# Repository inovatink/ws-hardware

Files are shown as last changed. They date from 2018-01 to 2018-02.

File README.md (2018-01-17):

# Wearable Sensor Hardware

## Description

In this repository you can find all of the necessary materials to; 
- understand what was done 
- manufacture hardware (Electronics + 3D print)
- program Arduino bootloader
- setup microcontroller

# Important Notice

If you decide to modify any parts of the project make sure you keep it open source and share with us. Keep up the good work.

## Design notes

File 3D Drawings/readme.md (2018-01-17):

# 3D Drawings

Here are Solidworks parts of bottom and top piece of wearable sensor enclosure and also STL parts that can be 3D printed.

The sensor enclosure consists of 2 parts, top and bottom;

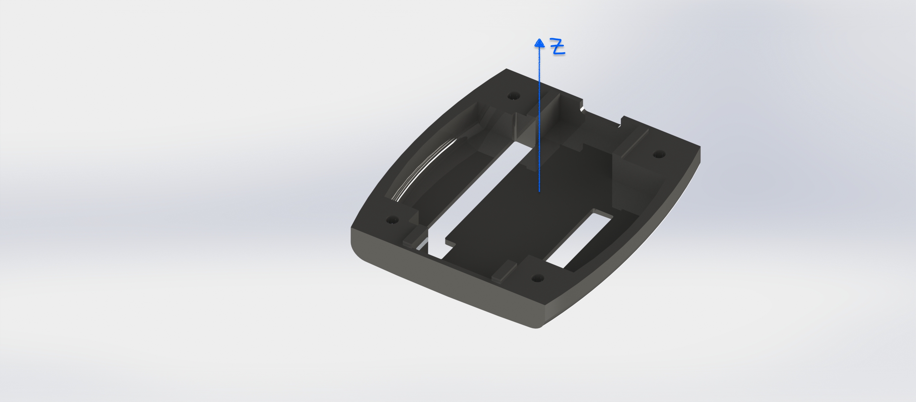
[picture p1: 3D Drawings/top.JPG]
Top
Top: 

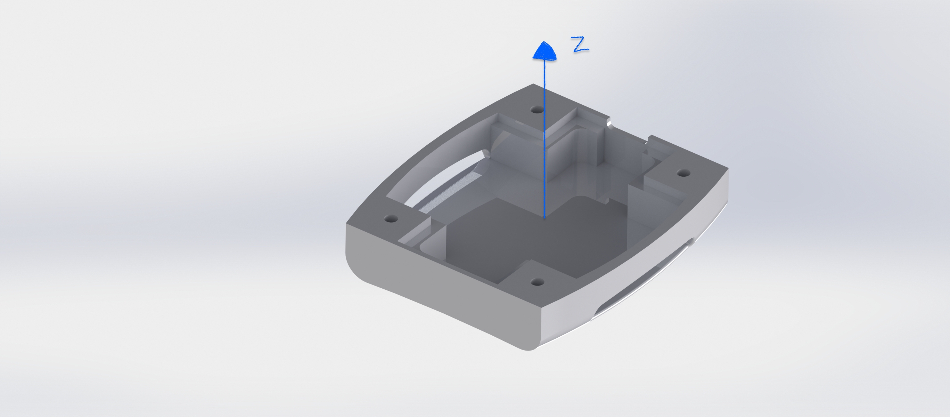
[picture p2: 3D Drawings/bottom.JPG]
Bottom
Bottom:

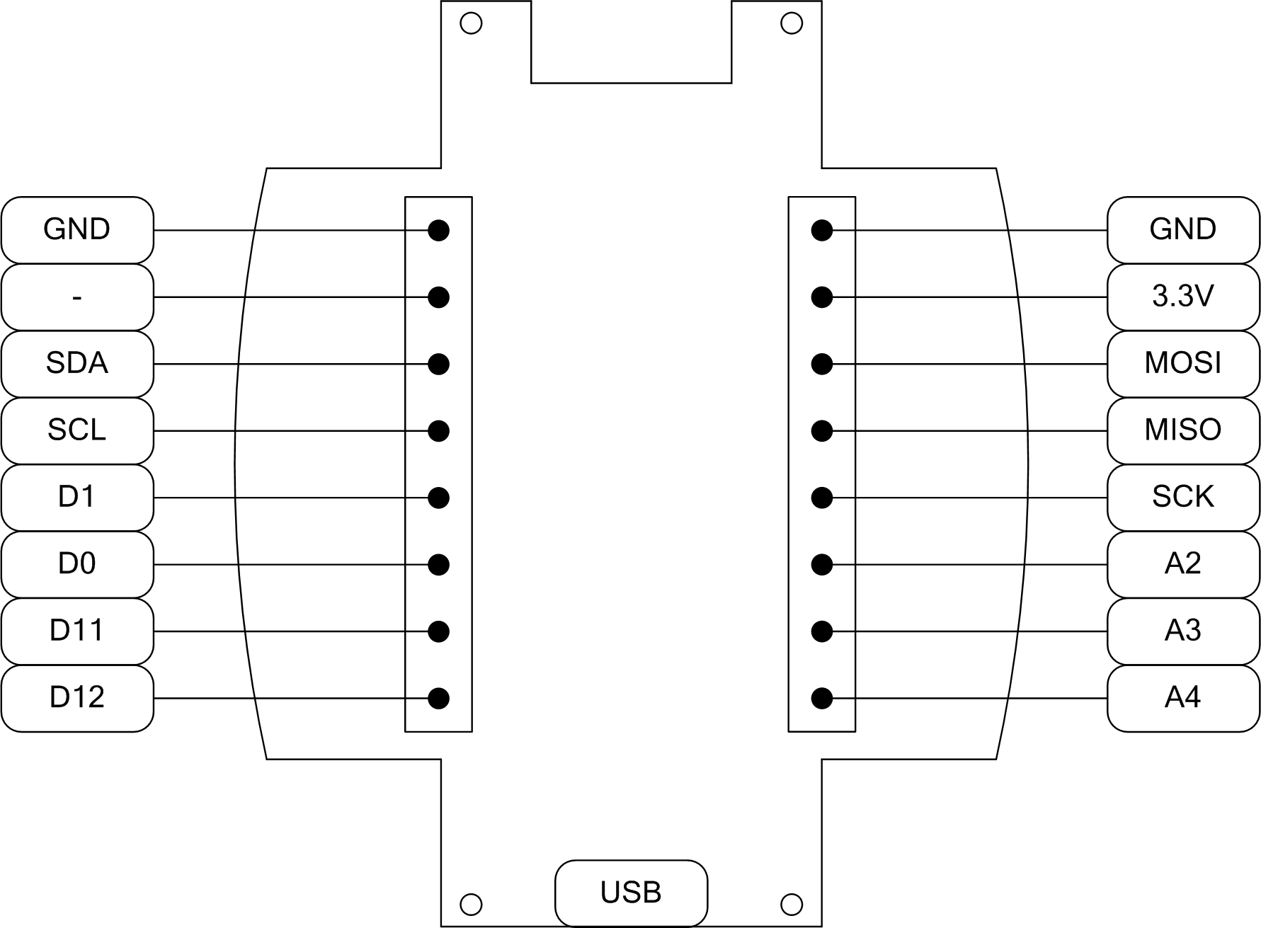
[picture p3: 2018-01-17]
ws_v2_external_pinout.png

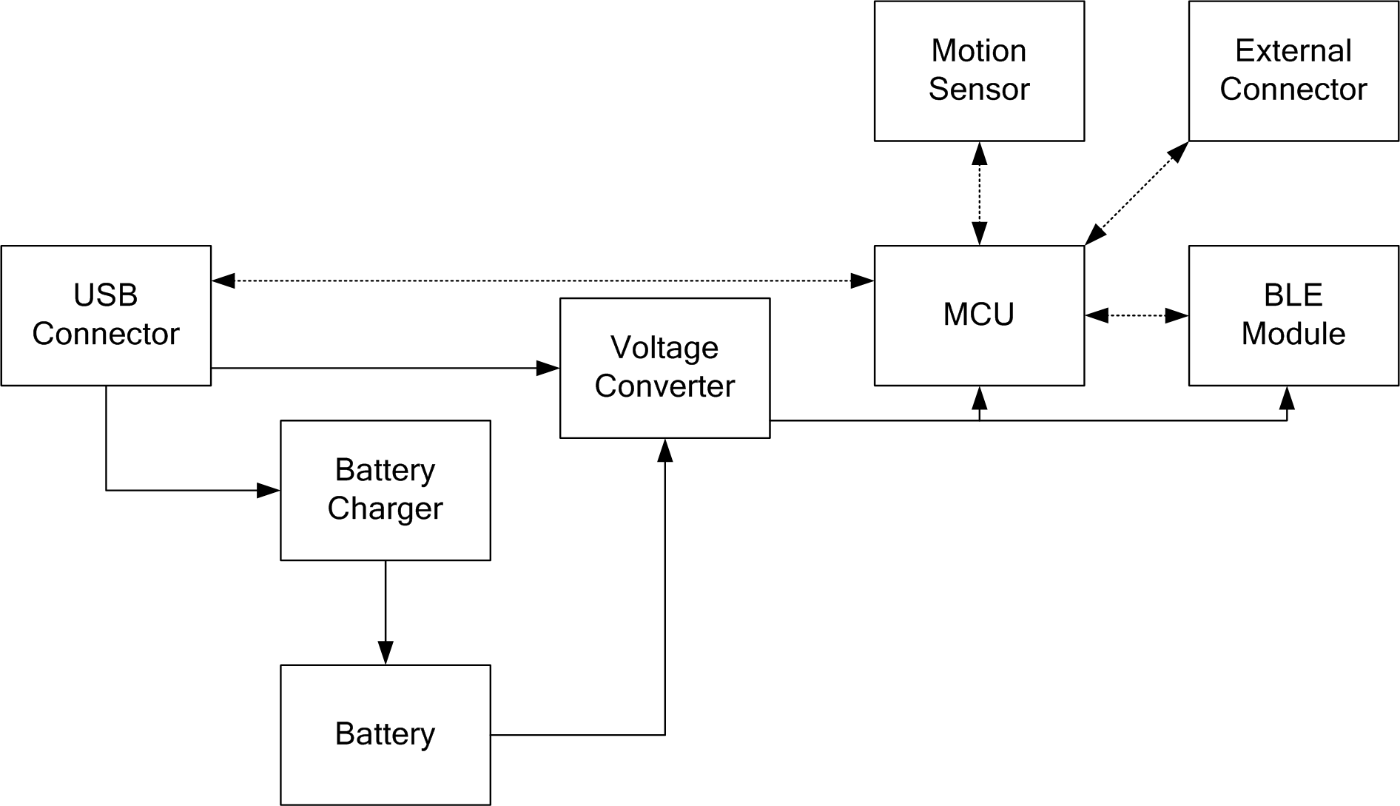
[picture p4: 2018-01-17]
ws_v2_block_diagram.png

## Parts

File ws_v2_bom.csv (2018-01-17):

Part | Value | Package | Mfg. Part No. | Datasheet
B1 | button | KMR2 | KMR231NG LFS | https://www.ckswitches.com/media/1479/kmr2.pdf
C1 | 0.1u | C0805
C2 | 10u | C0805
C3 | 0.1u | C0805
C4 | 10u | C0805
C5 | 0.1u | C0805
C6 | 10u | C0805
C7 | 0.1u | C0805
C8 | 10u | C0805
C9 | 0.1u | C0805
C11 | 0.1u | C0805
C12 | 1u | "C0805"
C13 | 0.1u | C0805
C14 | 0.1u | C0805
C15 | 0.1u | C0805
C17 | 0.1u | C0805
C18 | 0.1u | C0805
C19 | 0.1u | C0805
C20 | 0.1u | C0805
D1 |  | SOD-323F | ZLLS410TA | https://www.diodes.com/assets/Datasheets/ZLLS410.pdf
IC1 | RN4871 | RN4871 | RN4871-V/RM118 | http://ww1.microchip.com/downloads/en/DeviceDoc/50002489C.pdf
IC2 | ATSAMD21G-A | TQFP-48 | ATSAMD21G18A-AUT | http://ww1.microchip.com/downloads/en/DeviceDoc/40001882A.pdf
IC3 | AP2112K-3.3V | SOT23-5 | AP2112K-3.3TRG1 | https://www.diodes.com/assets/Datasheets/AP2112.pdf
IC4 | MCP73831 | SOT23-5 | MCP73831T-2ACI/OT | http://ww1.microchip.com/downloads/en/DeviceDoc/20001984g.pdf
IC5 | MPU-9250 |  | MPU-9250 | https://store.invensense.com/datasheets/invensense/MPU9250REV1.0.pdf
J1 |  | 1X08_SMD_MALE | 91601-308LF | https://cdn.amphenol-icc.com/media/wysiwyg/files/drawing/91601.pdf
J2 |  | 1X08_SMD_MALE | 91601-308LF | https://cdn.amphenol-icc.com/media/wysiwyg/files/drawing/91601.pdf
L1 | ferrite_bead | L0805 | MH2029-601Y | http://www.bourns.com/docs/Product-Datasheets/mh.pdf
LED1 | AMBER | CHIP-LED0805
LED2 | GREEN | CHIP-LED0805
LED3 | BLUE | CHIP-LED0805
R1 | 10k | R0805
R2 | tbd | R0805
R3 | tbd | R0805
R4 | 100k | R0805
R5 | 100k | R0805
R6 | tbd | R0805
R7 | tbd | R0805
R8 | 100k | R0805
R12 | 100k | R0805
R13 | 10k | R0805
R14 | 10k | R0805
X1 | USB | USB - micro B | 10118194-0001LF | https://cdn.amphenol-icc.com/media/wysiwyg/files/documentation/datasheet/inputoutput/io_usb_micro.pdf
X2 | BATTERY | JST_2PIN-SMT-RA | S2B-PH-SM4-TB(LF)(SN) | http://www.jst-mfg.com/product/pdf/eng/ePH.pdf
X3 | DEBUG | 2X5-PTH-1.27MM | 20021111-00010T4LF | https://cdn.amphenol-icc.com/media/wysiwyg/files/drawing/20021111.pdf
X4 | HRM | 1X5-PTH-2.54MM

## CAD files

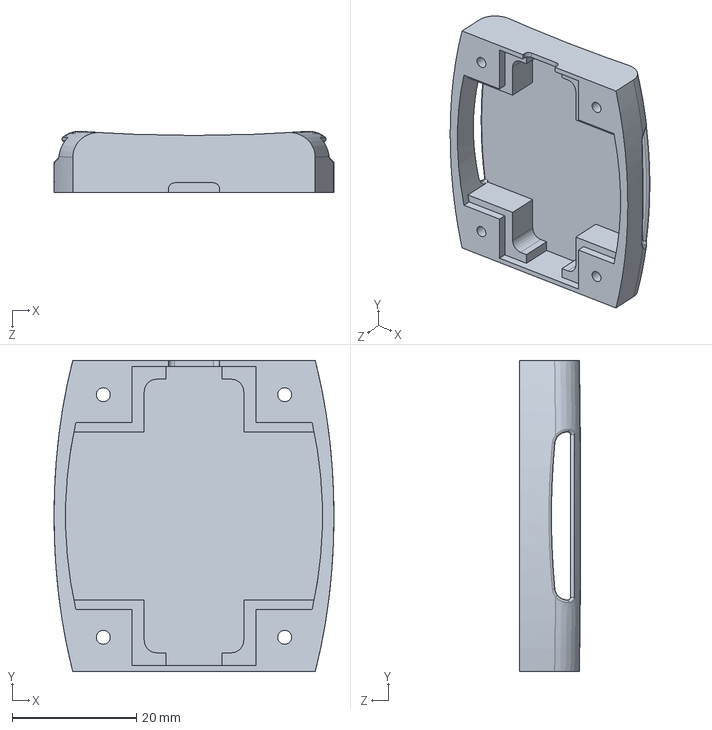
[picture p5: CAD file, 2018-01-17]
3D Drawings/Solidworks Files/Bottom.SLDPRT
45.0 x 50.0 x 9.86 mm

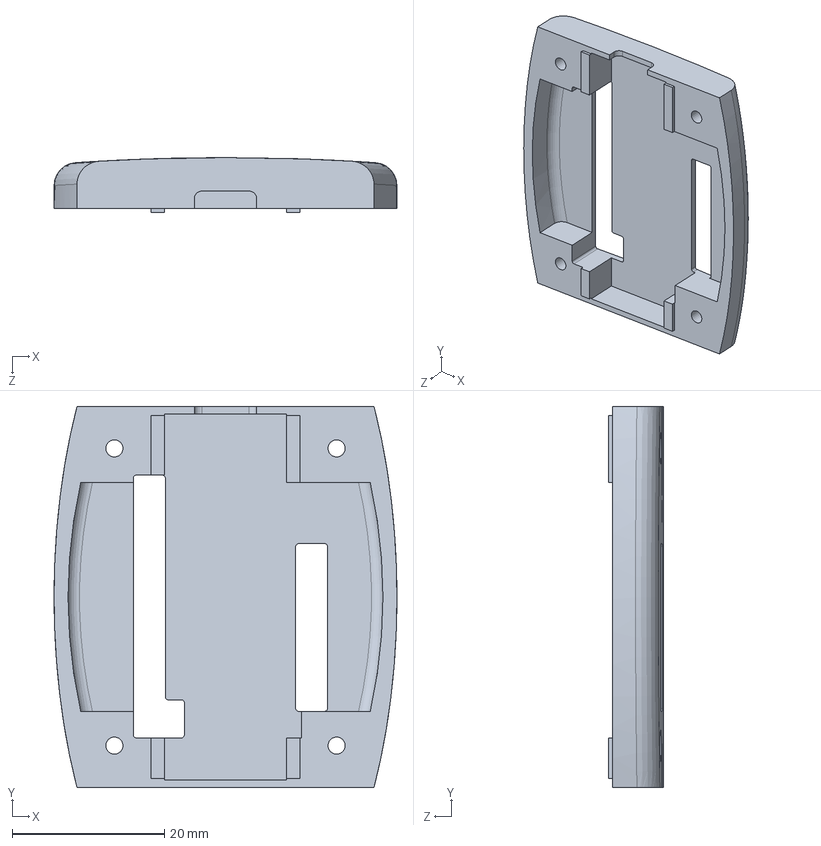
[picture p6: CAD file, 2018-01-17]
3D Drawings/Solidworks Files/Top.SLDPRT
45.0 x 50.0 x 7.20 mm

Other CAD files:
3D Drawings/STL Files/Bottom.STL
3D Drawings/STL Files/Top.STL

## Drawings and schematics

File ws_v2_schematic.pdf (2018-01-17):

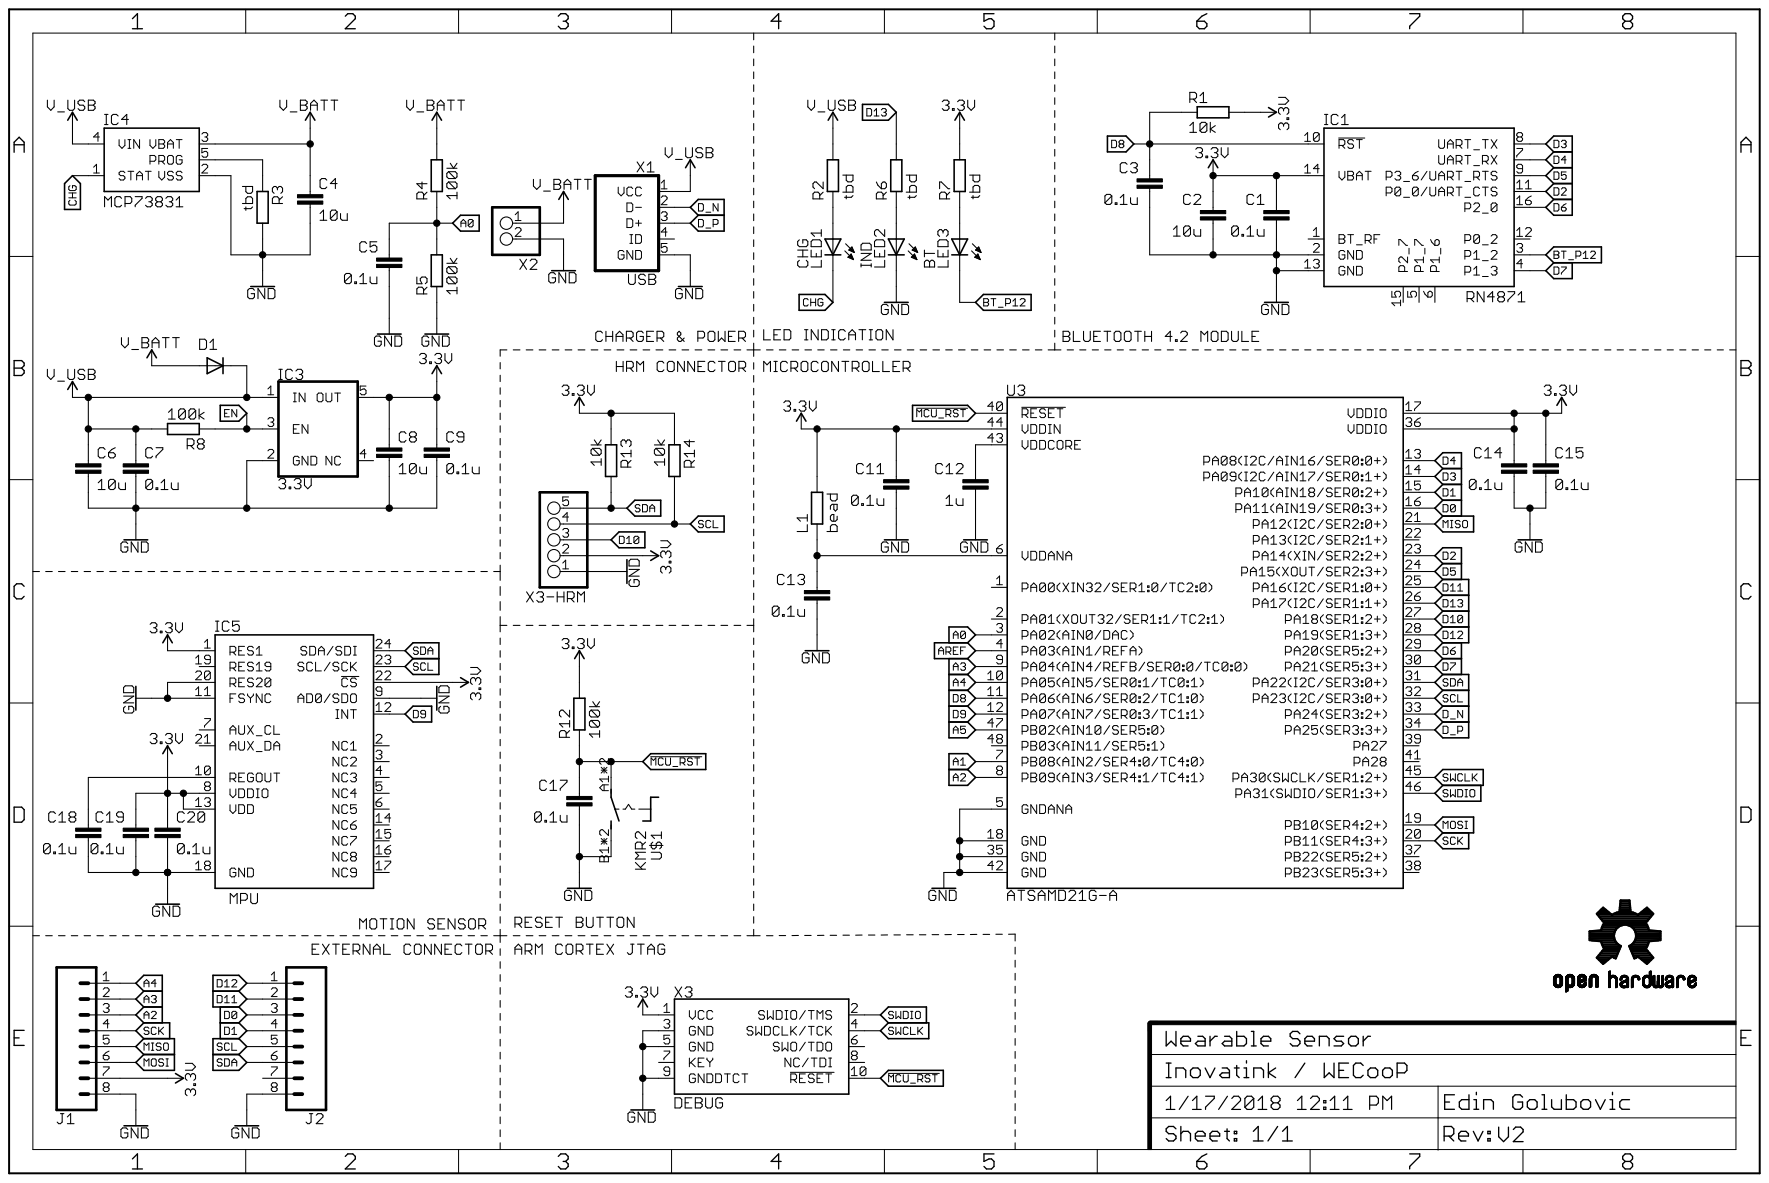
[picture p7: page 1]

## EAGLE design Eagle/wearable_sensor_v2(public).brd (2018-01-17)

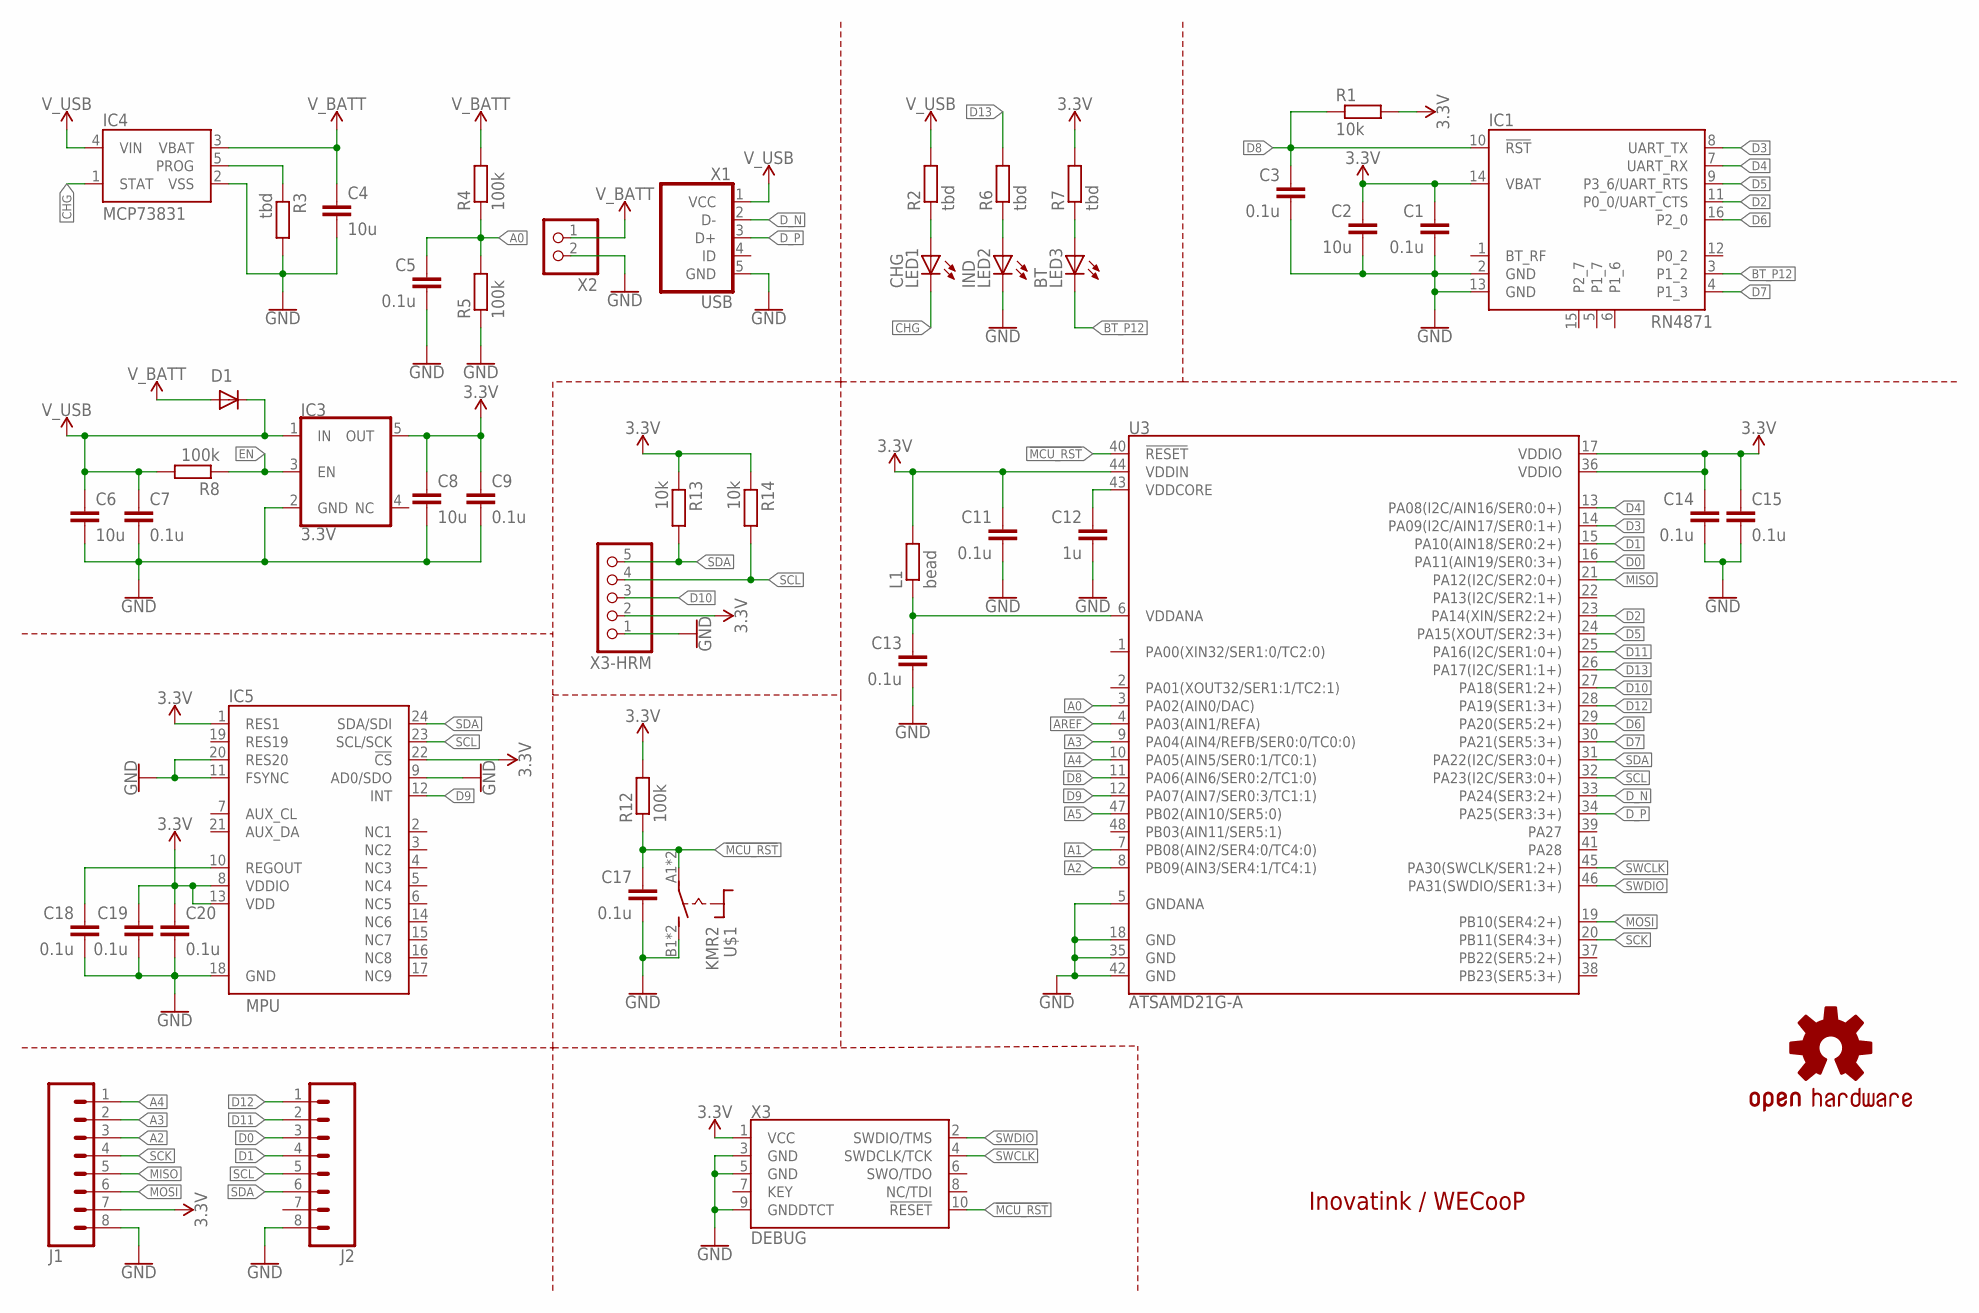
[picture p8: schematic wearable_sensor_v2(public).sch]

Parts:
C1, C3, C5, C7, C9, C11, C13, C14, C15, C17, C18, C19, C20: 0.1u; C0805
C2, C4, C6, C8: 10u; C0805
C12: 1u; C0805
D1: DIODESOD-323F; SOD-323F
IC1: RN4871
IC3: 3.3V; SOT23-5
IC4: MCP73831; SOT23-5
IC5: MPU; MPU9250
J1, J2: CONN_08SMD-MALE; 1X08_SMD_MALE
L1: bead; R0805
LED1: CHG; CHIP-LED0805
LED2: IND; CHIP-LED0805
LED3: BT; CHIP-LED0805
LOGO1: OSHW-LOGOMINI; OSHW-LOGO-MINI
R1, R13, R14: 10k; R0805
R2, R3, R6, R7: tbd; R0805
R4, R5, R8, R12: 100k; R0805
U3: ATSAMD21G-A; TQFP-48
U$1: KMR2
X1: USB; 10118194-0001LF
X2: JST_2PIN-SMT-RA; JST-PH-2-SMT-RA
X3: DEBUG; 2X5-PTH-1.27MM
X3-HRM: PINHD-1X5; 1X05

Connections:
3.3V: C1.1, C2.1, C8.1, C9.1, C11.1, C14.1, C15.1, C19.1, C20.1, IC1.14 (VBAT), IC3.5 (OUT), IC5.1 (RES1), IC5.8 (VDDIO), IC5.13 (VDD), IC5.22 (!CS), J1.7, L1.2, R1.2, R7.2, R12.2, R13.1, R14.1, U3.17 (VDDIO), U3.36 (VDDIO), U3.44 (VDDIN), X3.1 (VCC), X3-HRM.2
!MCU_RST: C17.1, R12.1, U3.40 (!RESET!), U$1.A1, U$1.A2, X3.10 (!RESET)
A0: C5.1, R4.1, R5.2, U3.3 (PA02(AIN0/DAC))
A1: U3.7 (PB08(AIN2/SER4:0/TC4:0))
A2: J1.3, U3.8 (PB09(AIN3/SER4:1/TC4:1))
A3: J1.2, U3.9 (PA04(AIN4/REFB/SER0:0/TC0:0))
A4: J1.1, U3.10 (PA05(AIN5/SER0:1/TC0:1))
A5: U3.47 (PB02(AIN10/SER5:0))
AREF: U3.4 (PA03(AIN1/REFA))
BT_P12: IC1.3 (P1_2), LED3.C
CHG: IC4.1 (STAT), LED1.C
D0: J2.3, U3.16 (PA11(AIN19/SER0:3+))
D1: J2.4, U3.15 (PA10(AIN18/SER0:2+))
D2: IC1.11 (P0_0/UART_CTS), U3.23 (PA14(XIN/SER2:2+))
D3: IC1.8 (UART_TX), U3.14 (PA09(I2C/AIN17/SER0:1+))
D4: IC1.7 (UART_RX), U3.13 (PA08(I2C/AIN16/SER0:0+))
D5: IC1.9 (P3_6/UART_RTS), U3.24 (PA15(XOUT/SER2:3+))
D6: IC1.16 (P2_0), U3.29 (PA20(SER5:2+))
D7: IC1.4 (P1_3), U3.30 (PA21(SER5:3+))
D8: C3.1, IC1.10 (!RST), R1.1, U3.11 (PA06(AIN6/SER0:2/TC1:0))
D9: IC5.12 (INT), U3.12 (PA07(AIN7/SER0:3/TC1:1))
D10: U3.27 (PA18(SER1:2+)), X3-HRM.3
D11: J2.2, U3.25 (PA16(I2C/SER1:0+))
D12: J2.1, U3.28 (PA19(SER1:3+))
D13: R6.2, U3.26 (PA17(I2C/SER1:1+))
D_N: U3.33 (PA24(SER3:2+)), X1.2 (D-)
D_P: U3.34 (PA25(SER3:3+)), X1.3 (D+)
EN: IC3.3 (EN), R8.1
GND: C1.2, C2.2, C3.2, C4.2, C5.2, C6.2, C7.2, C8.2, C9.2, C11.2, C12.2, C13.2, C14.2, C15.2, C17.2, C18.2, C19.2, C20.2, IC1.2 (GND), IC1.13 (GND), IC3.2 (GND), IC4.2 (VSS), IC5.9 (AD0/SDO), IC5.11 (FSYNC), IC5.18 (GND), IC5.20 (RES20), J1.8, J2.8, LED2.C, R3.2, R5.1, U3.5 (GNDANA), U3.18 (GND), U3.35 (GND), U3.42 (GND), U$1.B1 (S), U$1.B2 (S), X1.5 (GND), X2.2 (1), X3.3 (GND), X3.5 (GND), X3.9 (GNDDTCT), X3-HRM.1
MISO: J1.5, U3.21 (PA12(I2C/SER2:0+))
MOSI: J1.6, U3.19 (PB10(SER4:2+))
unnamed: LED2.A, R6.1
unnamed: LED1.A, R2.1
unnamed: IC4.5 (PROG), R3.1
unnamed: LED3.A, R7.1
unnamed: C18.1, IC5.10 (REGOUT)
unnamed: C13.1, L1.1, U3.6 (VDDANA)
unnamed: C12.1, U3.43 (VDDCORE)
SCK: J1.4, U3.20 (PB11(SER4:3+))
SCL: IC5.23 (SCL/SCK), J2.5, R14.2, U3.32 (PA23(I2C/SER3:0+)), X3-HRM.4
SDA: IC5.24 (SDA/SDI), J2.6, R13.2, U3.31 (PA22(I2C/SER3:0+)), X3-HRM.5
SWCLK: U3.45 (PA30(SWCLK/SER1:2+)), X3.4 (SWDCLK/TCK)
SWDIO: U3.46 (PA31(SWDIO/SER1:3+)), X3.2 (SWDIO/TMS)
V_BATT: C4.1, D1.A, IC4.3 (VBAT), R4.2, X2.1 (2)
V_USB: C6.1, C7.1, D1.C, IC3.1 (IN), IC4.4 (VIN), R2.2, R8.2, X1.1 (VCC)

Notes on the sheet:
Inovatink / WECooP

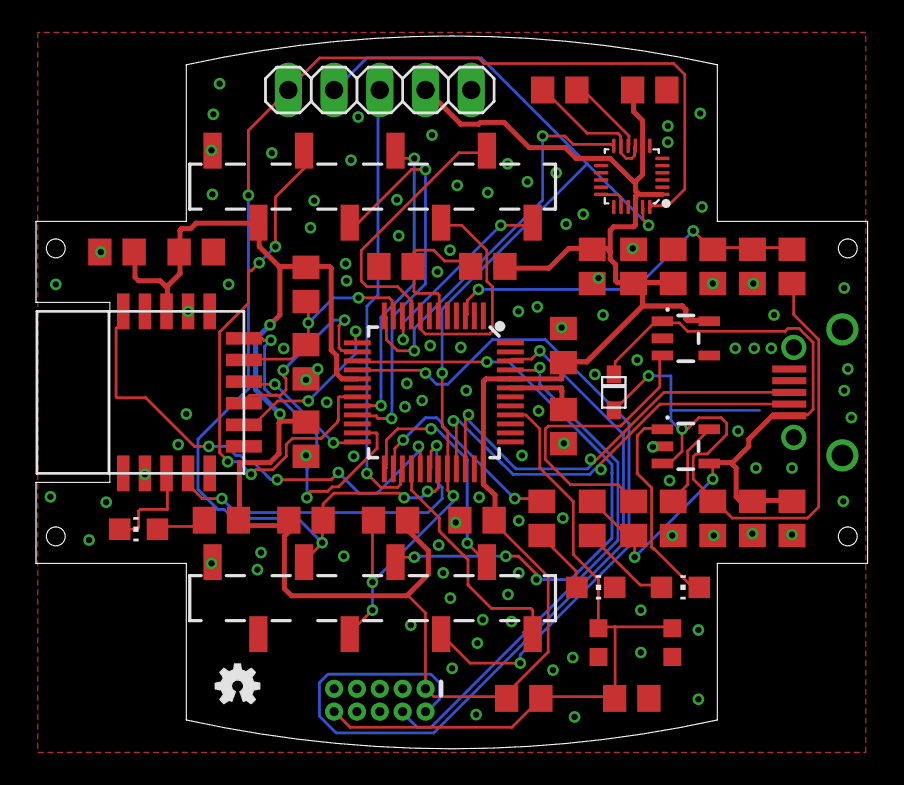
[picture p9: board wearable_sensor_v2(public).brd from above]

Board: 2 copper layers, 46.2 x 39.6 mm, 47 parts (1 on the bottom side), 42 nets.

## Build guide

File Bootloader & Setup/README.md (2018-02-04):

# Bootloader and Initial Setup

## Necessary Tools

- ARM Cortex JTAG (ATMEL-ICE, SAM-ICE or equivalent )

## Procedure

Below procedure explains how to program the bootloader into the wearable sensor board and how to change variant.cpp, variant.h and boards.txt files in order to have wearable sensor working with Arduino enviroment.

> If you already have board with Arduino bootloader you can skip step 1.

> This repo  includes the changed boards.txt, variant.cpp and varian.h files. This files were changed for Arduino version 1.8.5 (Windows) and Arduino SAMD Boards package version 1.6.17. If you have different version of Arduino and SAMD board package it is recommended that you go through procedure given below. Otherwise just download these files and replace the original ones in the corresponding folders and you will be all set.

1. Flash Board with bootloader circuitplay_m0_samd21g18_sam_ba.bin from https://github.com/arduino/ArduinoCore-samd/tree/master/bootloaders/circuitplay (also found in this repo)
2. Install latest Arduino IDE 
3. Install latest SAMD board package (Boards Manager)
4. In AppData\Local\Arduino15\packages\arduino\hardware\samd\1.6.xx folder in boards.txt file under the section named # Arduino/Genuino Zero (Native USB Port) insert -DCRYSTALLESS flag in; 	
```cpp 
arduino_zero_native.build.extra_flags=-D__SAMD21G18A__ {build.usb_flags}
```
This operation shoud result in line like shown below;

```cpp
arduino_zero_native.build.extra_flags= -DCRYSTALLESS -D__SAMD21G18A__ {build.usb_flags}
```

5. In variant.cpp from \packages\arduino\hardware\samd\1.6.xx\variants\arduino_zero change pin description in PinDescription g_APinDescription

- Comment out:
```cpp
{ PORTA,  9, PIO_TIMER, (PIN_ATTR_DIGITAL|PIN_ATTR_PWM|PIN_ATTR_TIMER), No_ADC_Channel, PWM0_CH1, TCC0_CH1, EXTERNAL_INT_9 },]
{ PORTA,  8, PIO_TIMER, (PIN_ATTR_DIGITAL|PIN_ATTR_PWM|PIN_ATTR_TIMER), No_ADC_Channel, PWM0_CH0, TCC0_CH0, EXTERNAL_INT_NMI },
```

- Replace with
```cpp
{ PORTA,  9, PIO_SERCOM_ALT, (PIN_ATTR_DIGITAL), No_ADC_Channel,NOT_ON_PWM, NOT_ON_TIMER, EXTERNAL_INT_9 },
{ PORTA,  8, PIO_SERCOM_ALT, (PIN_ATTR_DIGITAL), No_ADC_Channel, NOT_ON_PWM, NOT_ON_TIMER, EXTERNAL_INT_NMI },
```
- Add following code at the end of variant.cpp
```cpp
Uart Serial2( &sercom2, PIN_SERIAL2_RX, PIN_SERIAL2_TX, PAD_SERIAL2_RX, PAD_SERIAL2_TX);		

void SERCOM2_Handler(){
	Serial2.IrqHandler();
	}
```

6. In variant.h under the same folder add following code in the SERCOM DEFINITION
```cpp
extern Uart Serial2;    // Serial2 definition
```

- Also add serial2 pin definition as shown below

```cpp	
#define PIN_SERIAL2_RX       (3ul)                 // Pin description number for PIO_SERCOM on D3
#define PIN_SERIAL2_TX       (4ul)                 // Pin description number for PIO_SERCOM on D4
#define PAD_SERIAL2_TX       (UART_TX_PAD_0)       // SERCOM pad 0
#define PAD_SERIAL2_RX       (SERCOM_RX_PAD_1)     // SERCOM pad 1`
```

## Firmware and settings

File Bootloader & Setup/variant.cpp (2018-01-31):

/*
  Copyright (c) 2014-2015 Arduino LLC.  All right reserved.

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
  You should have received a copy of the GNU Lesser General Public
  License along with this library; if not, write to the Free Software
  Foundation, Inc., 51 Franklin St, Fifth Floor, Boston, MA  02110-1301  USA
*/
/*
 * +------------+------------------+--------+-----------------+--------------------------------------------------------------------------------------------------------
 * + Pin number +  ZERO Board pin  |  PIN   | Label/Name      | Comments (* is for default peripheral in use)
 * +------------+------------------+--------+-----------------+--------------------------------------------------------------------------------------------------------
 * |            | Digital Low      |        |                 |
 * +------------+------------------+--------+-----------------+--------------------------------------------------------------------------------------------------------
 * | 0          | 0 -> RX          |  PA11  |                 | EIC/EXTINT[11] ADC/AIN[19]           PTC/X[3] *SERCOM0/PAD[3]  SERCOM2/PAD[3]  TCC0/WO[3]  TCC1/WO[1]
 * | 1          | 1 <- TX          |  PA10  |                 | EIC/EXTINT[10] ADC/AIN[18]           PTC/X[2] *SERCOM0/PAD[2]                  TCC0/WO[2]  TCC1/WO[0]
 * | 2          | 2                |  PA14  |                 | EIC/EXTINT[14]                                 SERCOM2/PAD[2]  SERCOM4/PAD[2]  TC3/WO[0]   TCC0/WO[4]
 * | 3          | ~3               |  PA09  |                 | EIC/EXTINT[9]  ADC/AIN[17]           PTC/X[1]  SERCOM0/PAD[1]  SERCOM2/PAD[1] *TCC0/WO[1]  TCC1/WO[3]
 * | 4          | ~4               |  PA08  |                 | EIC/NMI        ADC/AIN[16]           PTC/X[0]  SERCOM0/PAD[0]  SERCOM2/PAD[0] *TCC0/WO[0]  TCC1/WO[2]
 * | 5          | ~5               |  PA15  |                 | EIC/EXTINT[15]                                 SERCOM2/PAD[3]  SERCOM4/PAD[3] *TC3/WO[1]   TCC0/WO[5]
 * | 6          | ~6               |  PA20  |                 | EIC/EXTINT[4]                        PTC/X[8]  SERCOM5/PAD[2]  SERCOM3/PAD[2]             *TCC0/WO[6]
 * | 7          | 7                |  PA21  |                 | EIC/EXTINT[5]                        PTC/X[9]  SERCOM5/PAD[3]  SERCOM3/PAD[3]              TCC0/WO[7]
 * +------------+------------------+--------+-----------------+--------------------------------------------------------------------------------------------------------
 * |            | Digital High     |        |                 |
 * +------------+------------------+--------+-----------------+--------------------------------------------------------------------------------------------------------
 * | 8          | ~8               |  PA06  |                 | EIC/EXTINT[6]  ADC/AIN[6]  AC/AIN[2] PTC/Y[4]  SERCOM0/PAD[2]                 *TCC1/WO[0]
 * | 9          | ~9               |  PA07  |                 | EIC/EXTINT[7]  ADC/AIN[7]  AC/AIN[3] PTC/Y[5]  SERCOM0/PAD[3]                 *TCC1/WO[1]
 * | 10         | ~10              |  PA18  |                 | EIC/EXTINT[2]                        PTC/X[6] +SERCOM1/PAD[2]  SERCOM3/PAD[2] *TC3/WO[0]    TCC0/WO[2]
 * | 11         | ~11              |  PA16  |                 | EIC/EXTINT[0]                        PTC/X[4] +SERCOM1/PAD[0]  SERCOM3/PAD[0] *TCC2/WO[0]   TCC0/WO[6]
 * | 12         | ~12              |  PA19  |                 | EIC/EXTINT[3]                        PTC/X[7] +SERCOM1/PAD[3]  SERCOM3/PAD[3]  TC3/WO[1]   *TCC0/WO[3]
 * | 13         | ~13              |  PA17  | LED             | EIC/EXTINT[1]                        PTC/X[5] +SERCOM1/PAD[1]  SERCOM3/PAD[1] *TCC2/WO[1]   TCC0/WO[7]
 * +------------+------------------+--------+-----------------+--------------------------------------------------------------------------------------------------------
 * |            | Analog Connector |        |                 |
 * +------------+------------------+--------+-----------------+--------------------------------------------------------------------------------------------------------
 * | 14         | A0               |  PA02  | A0              | EIC/EXTINT[2] *ADC/AIN[0]  DAC/VOUT  PTC/Y[0]
 * | 15         | A1               |  PB08  | A1              | EIC/EXTINT[8] *ADC/AIN[2]            PTC/Y[14] SERCOM4/PAD[0]                  TC4/WO[0]
 * | 16         | A2               |  PB09  | A2              | EIC/EXTINT[9] *ADC/AIN[3]            PTC/Y[15] SERCOM4/PAD[1]                  TC4/WO[1]
 * | 17         | A3               |  PA04  | A3              | EIC/EXTINT[4] *ADC/AIN[4]  AC/AIN[0] PTC/Y[2]  SERCOM0/PAD[0]                  TCC0/WO[0]
 * | 18         | A4               |  PA05  | A4              | EIC/EXTINT[5] *ADC/AIN[5]  AC/AIN[1] PTC/Y[5]  SERCOM0/PAD[1]                  TCC0/WO[1]
 * | 19         | A5               |  PB02  | A5              | EIC/EXTINT[2] *ADC/AIN[10]           PTC/Y[8]  SERCOM5/PAD[0]
 * +------------+------------------+--------+-----------------+--------------------------------------------------------------------------------------------------------
 * |            | Wire             |        |                 |
 * +------------+------------------+--------+-----------------+--------------------------------------------------------------------------------------------------------
 * | 20         | SDA              |  PA22  | SDA             | EIC/EXTINT[6]                        PTC/X[10] *SERCOM3/PAD[0] SERCOM5/PAD[0] TC4/WO[0] TCC0/WO[4]
 * | 21         | SCL              |  PA23  | SCL             | EIC/EXTINT[7]                        PTC/X[11] *SERCOM3/PAD[1] SERCOM5/PAD[1] TC4/WO[1] TCC0/WO[5]
 * +------------+------------------+--------+-----------------+--------------------------------------------------------------------------------------------------------
 * |            |SPI (Legacy ICSP) |        |                 |
 * +------------+------------------+--------+-----------------+--------------------------------------------------------------------------------------------------------
 * | 22         | 1                |  PA12  | MISO            | EIC/EXTINT[12] SERCOM2/PAD[0] *SERCOM4/PAD[0] TCC2/WO[0] TCC0/WO[6]
 * |            | 2                |        | 5V0             |
 * | 23         | 4                |  PB10  | MOSI            | EIC/EXTINT[10]                *SERCOM4/PAD[2] TC5/WO[0]  TCC0/WO[4]
 * | 24         | 3                |  PB11  | SCK             | EIC/EXTINT[11]                *SERCOM4/PAD[3] TC5/WO[1]  TCC0/WO[5]
 * |            | 5                |        | RESET           |
 * |            | 6                |        | GND             |
 * +------------+------------------+--------+-----------------+--------------------------------------------------------------------------------------------------------
 * |            | LEDs             |        |                 |
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

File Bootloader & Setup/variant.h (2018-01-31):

/*
  Copyright (c) 2014-2015 Arduino LLC.  All right reserved.

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
  You should have received a copy of the GNU Lesser General Public
  License along with this library; if not, write to the Free Software
  Foundation, Inc., 51 Franklin St, Fifth Floor, Boston, MA  02110-1301  USA
*/

#ifndef _VARIANT_ARDUINO_ZERO_
#define _VARIANT_ARDUINO_ZERO_

// The definitions here needs a SAMD core >=1.6.10
#define ARDUINO_SAMD_VARIANT_COMPLIANCE 10610

/*----------------------------------------------------------------------------
 *        Definitions
 *----------------------------------------------------------------------------*/

/** Frequency of the board main oscillator */
#define VARIANT_MAINOSC		(32768ul)

/** Master clock frequency */
#define VARIANT_MCK			  (48000000ul)

/*----------------------------------------------------------------------------
 *        Headers
 *----------------------------------------------------------------------------*/

#include "WVariant.h"

#ifdef __cplusplus
#include "SERCOM.h"
#include "Uart.h"
#endif // __cplusplus

#ifdef __cplusplus
extern "C"
{
#endif // __cplusplus

/*----------------------------------------------------------------------------
 *        Pins
 *----------------------------------------------------------------------------*/

// Number of pins defined in PinDescription array
#define PINS_COUNT           (26u)
#define NUM_DIGITAL_PINS     (20u)
#define NUM_ANALOG_INPUTS    (6u)
#define NUM_ANALOG_OUTPUTS   (1u)
#define analogInputToDigitalPin(p)  ((p < 6u) ? (p) + 14u : -1)

#define digitalPinToPort(P)        ( &(PORT->Group[g_APinDescription[P].ulPort]) )
#define digitalPinToBitMask(P)     ( 1 << g_APinDescription[P].ulPin )
//#define analogInPinToBit(P)        ( )
#define portOutputRegister(port)   ( &(port->OUT.reg) )
#define portInputRegister(port)    ( &(port->IN.reg) )
#define portModeRegister(port)     ( &(port->DIR.reg) )
#define digitalPinHasPWM(P)        ( g_APinDescription[P].ulPWMChannel != NOT_ON_PWM || g_APinDescription[P].ulTCChannel != NOT_ON_TIMER )

/*
 * digitalPinToTimer(..) is AVR-specific and is not defined for SAMD
 * architecture. If you need to check if a pin supports PWM you must
 * use digitalPinHasPWM(..).
 *
 * https://github.com/arduino/Arduino/issues/1833
 */
// #define digitalPinToTimer(P)

// LEDs
#define PIN_LED_13           (13u)
#define PIN_LED_RXL          (25u)
#define PIN_LED_TXL          (26u)
#define PIN_LED              PIN_LED_13
#define PIN_LED2             PIN_LED_RXL
#define PIN_LED3             PIN_LED_TXL
#define LED_BUILTIN          PIN_LED_13

/*
 * Analog pins
 */
#define PIN_A0               (14ul)
#define PIN_A1               (15ul)
#define PIN_A2               (16ul)
#define PIN_A3               (17ul)
#define PIN_A4               (18ul)
#define PIN_A5               (19ul)
#define PIN_DAC0             (14ul)

static const uint8_t A0  = PIN_A0;
static const uint8_t A1  = PIN_A1;
static const uint8_t A2  = PIN_A2;
static const uint8_t A3  = PIN_A3;
static const uint8_t A4  = PIN_A4;
static const uint8_t A5  = PIN_A5;
static const uint8_t DAC0 = PIN_DAC0;
#define ADC_RESOLUTION		12

// Other pins
#define PIN_ATN              (38ul)
static const uint8_t ATN = PIN_ATN;

/*
 * Serial interfaces
 */
// Serial (EDBG)
#define PIN_SERIAL_RX       (31ul)
#define PIN_SERIAL_TX       (30ul)
#define PAD_SERIAL_TX       (UART_TX_PAD_2)
#define PAD_SERIAL_RX       (SERCOM_RX_PAD_3)

// Serial1
#define PIN_SERIAL1_RX       (0ul)
#define PIN_SERIAL1_TX       (1ul)
#define PAD_SERIAL1_TX       (UART_TX_PAD_2)
#define PAD_SERIAL1_RX       (SERCOM_RX_PAD_3)

// Serial2
#define PIN_SERIAL2_RX       (3ul)                 // Pin description number for PIO_SERCOM on D3
#define PIN_SERIAL2_TX       (4ul)                 // Pin description number for PIO_SERCOM on D4
#define PAD_SERIAL2_TX       (UART_TX_PAD_0)       // SERCOM pad 0
#define PAD_SERIAL2_RX       (SERCOM_RX_PAD_1)     // SERCOM pad 1`

/*
 * SPI Interfaces
 */
#define SPI_INTERFACES_COUNT 1

#define PIN_SPI_MISO         (22u)
#define PIN_SPI_MOSI         (23u)
#define PIN_SPI_SCK          (24u)
#define PERIPH_SPI           sercom4
#define PAD_SPI_TX           SPI_PAD_2_SCK_3
#define PAD_SPI_RX           SERCOM_RX_PAD_0

static const uint8_t SS	  = PIN_A2 ;	// SERCOM4 last PAD is present on A2 but HW SS isn't used. Set here only for reference.
static const uint8_t MOSI = PIN_SPI_MOSI ;
static const uint8_t MISO = PIN_SPI_MISO ;
static const uint8_t SCK  = PIN_SPI_SCK ;

/*
 * Wire Interfaces
 */
#define WIRE_INTERFACES_COUNT 1

#define PIN_WIRE_SDA         (20u)
#define PIN_WIRE_SCL         (21u)
#define PERIPH_WIRE          sercom3
#define WIRE_IT_HANDLER      SERCOM3_Handler

static const uint8_t SDA = PIN_WIRE_SDA;
static const uint8_t SCL = PIN_WIRE_SCL;

/*
 * USB
 */
#define PIN_USB_HOST_ENABLE (27ul)
#define PIN_USB_DM          (28ul)
#define PIN_USB_DP          (29ul)

/*
 * I2S Interfaces
 */
#define I2S_INTERFACES_COUNT 1

#define I2S_DEVICE          0
#define I2S_CLOCK_GENERATOR 3
#define PIN_I2S_SD          (9u)
#define PIN_I2S_SCK         (1u)
#define PIN_I2S_FS          (0u)

#ifdef __cplusplus
}
#endif

/*----------------------------------------------------------------------------
 *        Arduino objects - C++ only
 *----------------------------------------------------------------------------*/

#ifdef __cplusplus

/*	=========================
 *	===== SERCOM DEFINITION
 *	=========================
*/
extern SERCOM sercom0;
extern SERCOM sercom1;
extern SERCOM sercom2;
extern SERCOM sercom3;
extern SERCOM sercom4;
extern SERCOM sercom5;

extern Uart Serial;
extern Uart Serial1;
extern Uart Serial2;    // Serial2 definition

#endif

// These serial port names are intended to allow libraries and architecture-neutral
// sketches to automatically default to the correct port name for a particular type
// of use.  For example, a GPS module would normally connect to SERIAL_PORT_HARDWARE_OPEN,
// the first hardware serial port whose RX/TX pins are not dedicated to another use.
//
// SERIAL_PORT_MONITOR        Port which normally prints to the Arduino Serial Monitor
//
// SERIAL_PORT_USBVIRTUAL     Port which is USB virtual serial
//
// SERIAL_PORT_LINUXBRIDGE    Port which connects to a Linux system via Bridge library
//
// SERIAL_PORT_HARDWARE       Hardware serial port, physical RX & TX pins.
//
// SERIAL_PORT_HARDWARE_OPEN  Hardware serial ports which are open for use.  Their RX & TX
//                            pins are NOT connected to anything by default.
#define SERIAL_PORT_USBVIRTUAL      SerialUSB
#define SERIAL_PORT_MONITOR         Serial
// Serial has no physical pins broken out, so it's not listed as HARDWARE port
#define SERIAL_PORT_HARDWARE        Serial1
#define SERIAL_PORT_HARDWARE_OPEN   Serial1

#endif /* _VARIANT_ARDUINO_ZERO_ */

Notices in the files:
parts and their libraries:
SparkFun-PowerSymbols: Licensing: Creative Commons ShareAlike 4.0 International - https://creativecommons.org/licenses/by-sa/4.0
